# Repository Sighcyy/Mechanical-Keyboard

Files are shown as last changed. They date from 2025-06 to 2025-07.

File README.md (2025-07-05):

# Mechanical Keyboard

I designed a 60% Mechanical Keyboard featuring 60+ push-button switches, a rotary encoder, and keystabilizers for larger keycaps. It features an EC11 rotary encoder,  the Raspberry Pi Pico microcontroller, which was chosen for its small form factor and support for KMK firmware. The parts are populated on a custom PCB for tidy arrangement and good performance. The case is fully 3D printable, making the design easy to reproduce and customize. This keyboard provides a programmable  interface to enhance game control and portability rather than a larger keyboard. 

# Project Goal
This is my second official project, and the reason I wanted to implement this is that I wanted to work more in-depth with complex PCBs. Thus, I decided that a keyboard with a key matrix would be best, and routing all the switches would require using a lot more of the front-end and back-end copper layers, as well as vias. The purpose as a whole was not to try to follow any guides too much and just research a lot more in order to understand things. I felt like this would build a stronger sense of passion and understanding for the subject rather than blindly following a DIY guide. 

# BOM : 
*Shipping is included in the cost

*You may notice that I use Amazon a lot. I have Amazon Prime, and when comparing that to buying from somewhere with high shipping costs and potentially lower quality, I chose Amazon Prime.
| Name  | Vendor | Cost | Link |
| --- | --- | --- | --- |
| 1N4148WT Diodes x 100  | DigiKey  | ~$14.56  | [Link](https://www.digikey.com/en/products/detail/onsemi/1N4148WT/2094398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) |
| Keycaps ( Purple and Black)  | Amazon  | $14.59 |[Link](https://www.amazon.com/gp/product/B0C1BLFFKJ/ref=ewc_pr_img_1?smid=A2X78RSRFYCZMR&th=1)|
| PLA 1.75mm 3D Printer Filament  | Amazon  | $9.99  | [Link](https://www.amazon.com/Filament-Dimensional-Accuracy-Clogging-Cardboard/dp/B0DCJR8JTG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) |
| Rotary Encoder + Cap  | Amazon  | $8.88  | [Link](https://www.adafruit.com/product/5454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) |
| Gateron PCB Mounted Stabilizer  | Gateron  | $10.99  |[Link](https://www.gateron.com/products/gateron-pcb-mounted-stabilizer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) |
| Cherry MX Key Switches x 65 | Amazon  | $39.99  |[Link](https://www.amazon.com/Switches-Mechanical-Keyboards-Mounted-MX1AE1NN/dp/B09ZST8WMF?th=1) |
| Rasberry Pi Pico  | Amazon  | $8.99 | [Link](https://www.amazon.com/Raspberry-Pi-Pico/dp/B09KVB8LVR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) |
| M2.5 Screws | Amazon  | $3.78 | [Link](https://www.amazon.com/Stainless-Electrical-Attaching-Connectors-Furniture/dp/B0F1TX35J1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) |
| PCB | JLPCB  | $28.94 | [Link](https://cart.jlcpcb.com/quote?spm=Jlcpcb.Homepage.1006&spm=Jlcpcb.Homepage.1006) |

Approximate Total Cost:  $140.71

Rounded Total Cost (To Take Tax Into Account): $145

# PCB and Schematics Design




# CAD Model

Top Plate


Bottom Plate



Assembly with PCB


# Firmware Overview



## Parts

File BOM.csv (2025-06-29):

Name | Vendor | Cost | Link
1N4148WT Diodes x 100 | DigiKey | ~$14.56 | https://www.digikey.com/en/products/detail/onsemi/1N4148WT/2094398
Keycaps (Purple and Black) | Amazon | $14.59 | https://www.amazon.com/gp/product/B0C1BLFFKJ/ref=ewc_pr_img_1?smid=A2X78RSRFYCZMR&th=1
PLA 1.75mm 3D Printer Filament | Amazon | $9.99 | https://www.amazon.com/Filament-Dimensional-Accuracy-Clogging-Cardboard/dp/B0DCJR8JTG
Rotary Encoder + Cap | Amazon | $8.88 | https://www.adafruit.com/product/5454
Gateron PCB Mounted Stabilizer | Gateron | $10.99 | https://www.gateron.com/products/gateron-pcb-mounted-stabilizer?VariantsId=10538
Cherry MX Key Switches x 65 | Amazon | $39.99 | https://www.amazon.com/Switches-Mechanical-Keyboards-Mounted-MX1AE1NN/dp/B09ZST8WMF
Raspberry Pi Pico | Amazon | $8.99 | https://www.amazon.com/Raspberry-Pi-Pico/dp/B09KVB8LVR
M2.5 Screws | Amazon | $3.78 | https://www.amazon.com/Stainless-Electrical-Attaching-Connectors-Furniture/dp/B0F1TX35J1
PCB | JLCPCB | $28.94 | https://cart.jlcpcb.com/quote?spm=Jlcpcb.Homepage.1006
___ | Total | $140.71 | _______
___ | Realistic Total | $145 | _______

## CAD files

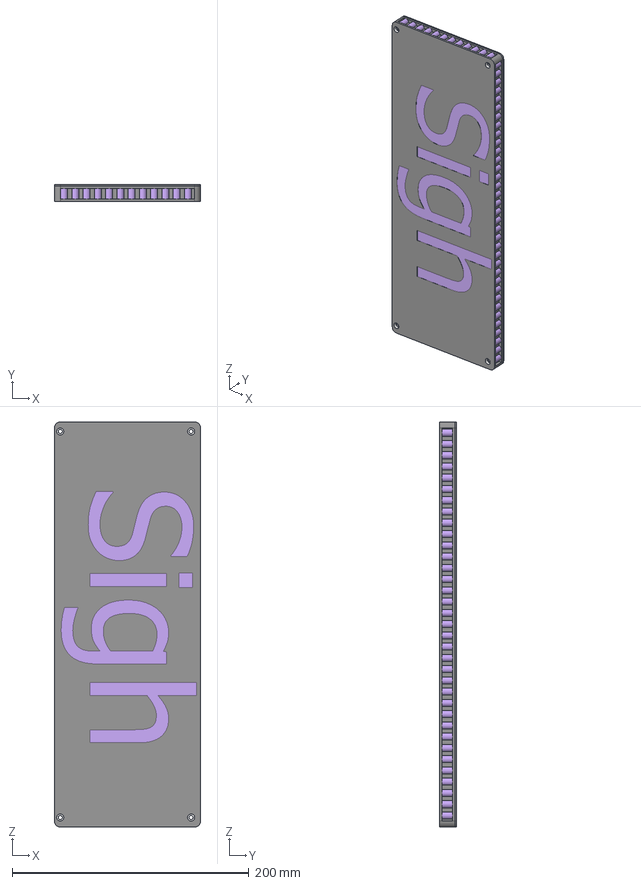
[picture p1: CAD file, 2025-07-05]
CAD/Assembly1.stp
123.5 x 14.5 x 341.8 mm
Top_Plate_Mkey
Bottom_Plate_MKey
D_SOD-523 x 63
FullSplit_Keyboard_PCB_PCB

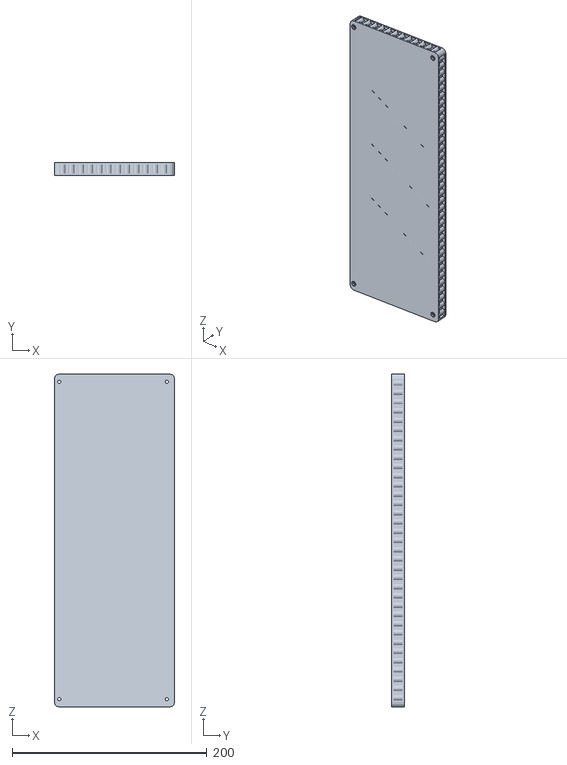
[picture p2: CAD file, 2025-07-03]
Production/Bottom_Plate_MKey.stl
123.5 x 13.0 x 341.8

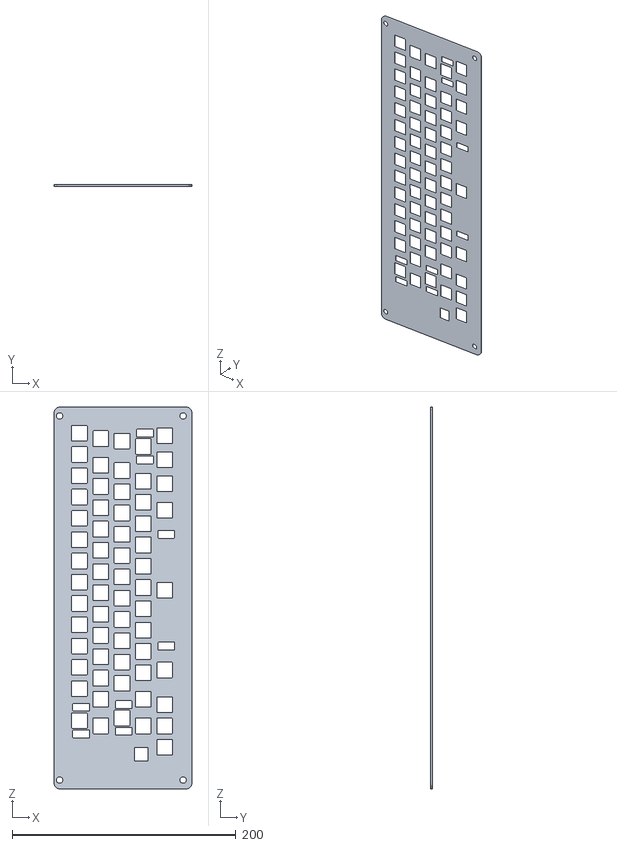
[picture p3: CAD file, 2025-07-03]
Production/Top_Plate_Mkey.stl
123.5 x 1.50 x 341.8

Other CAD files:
CAD/Bottom_Plate_MKey.stp
CAD/Top_Plate_Mkey.stp
CAD/Assembly1.iam
CAD/Assembly1.stl
CAD/Bottom_Plate_MKey.ipt
CAD/Bottom_Plate_MKey.stl
CAD/Top_Plate_Mkey.ipt

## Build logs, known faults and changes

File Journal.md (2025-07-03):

# June 20th, 2025
Time = ~4 hours

Today, I took the first step to advance to the next level in my keyboard journey. I started with a MacPad, but I did not use a matrix since I only had a few keys. Thus, my next project was going to be a Mechanical Keyboard.

Today, I conducted research and completed some overall planning for my project. With the matrix design, I had to take into account "ghosting", which I could easily avoid with some diodes. 

I did a couple of whiteboard drawings just to understand how many columns and rows I would need. Then I created my schematic based on my whiteboard drawing reference. 

D1_Schematics

I then went into what each key would represent so that I could get a better understanding of what the keyboard key layout would be like.

By doing this, I was able to remove some extra columns so that my keyboard would be much more portable.



Afterwards, I spent the rest of my time choosing the right footprints and placing all my parts properly on the PCB



# June 21th, 2025
Time = ~4 hours

Today, I focused on figuring out how to properly route all the key inputs on my PCB, which turned out to be more challenging than expected due to limited space and overlapping traces. I spent a lot of time experimenting with using the bottom copper layer and strategically placing vias to reduce congestion and avoid trace conflicts. This approach significantly streamlined the routing process and helped me finish the layout more efficiently. Along the way, I also picked up several helpful workflow shortcuts in KiCad, like quick via placement, net highlighting, and optimized trace routing, which should speed up my future designs and make the overall process smoother.



# June 22nd, 2025
Time = ~4 hours

Today was a productive day on the 3D modeling front, as I completed the main structure of the CAD model by designing both the top and bottom plates, following a similar approach to my earlier Macropad build. I used a keyboard layout editor to customize the key arrangement, then exported it as a DXF file to precisely cut switch holes into the top plate. While the design is still pretty minimal in terms of aesthetics, I decided to hold off on cosmetic features until later in the process. Instead, I shifted gears and began researching the firmware side—specifically how keymaps, layers, and matrix scanning are handled in microcontroller code—so I can better integrate the hardware and software components once the physical build is done.




# June 23rd, 2025
Time = ~4 hours

Today, I wrapped up writing the firmware for my keyboard using Python with the KMK framework. Thanks to the research I did yesterday on implementing diode-based matrix scanning and integrating a rotary encoder, the coding process went smoothly and efficiently. My prior experience with key assignments from my Macropad project also helped me set up the keymap and layers quickly. With the core functionality complete, I decided to spend some extra time refining the keyboard case design by adding custom inscriptions and decorative linings to give it a more polished and personalized look—details I believe will help the final product stand out both functionally and visually.




# June 24th, 2025
Time = ~4 hours

Since today was planned to be my final work session, I focused on wrapping up all remaining tasks to prepare for the build phase. I started by creating a complete Bill of Materials (BOM), which took some time due to the various key sizes and layout adjustments I had made—several non-standard key sizes required finding the right switch kit that could accommodate everything. I also researched PCB-mount stabilizers to match the layout and ensure proper key feel. In addition, I finalized my component list by selecting a compatible PCB, PLA filament for 3D printing the case, and a set of small screws and nuts to secure the top and bottom plates together. Most of the sourcing was done through Amazon, after comparing product specs and reviews to ensure everything matched my design needs. To finish off the day, I carefully reviewed the CAD model, double-checking all key dimensions and mounting points to catch any potential issues before manufacturing.

# July 7th, 2025
Big things, I wanted to do some quick changes. The keyboard itself was a little bland. Thus, I thought I would spend time today adding a little more uniqueness to it. I gave the edges of the keyboard a column-like aesthetic. The bottom had 3 large X's. Finally, for the actual top, I added the word 'PRIDE' in text. I thought it looked nice. 




Also, I wanted to make sure that if I painted it, I knew how it would loo,k so I added that into the design as well and finished up my design





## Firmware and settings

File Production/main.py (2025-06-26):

import board

from kmk.kmk_keyboard import KMKKeyboard
from kmk.scanners.keypad import KeysScanner
from kmk.keys import KC
from kmk.scanners import DiodeOrientation
from kmk.extensions.media_keys import MediaKeys
from kmk.modules.encoder import EncoderHandler
from kmk.modules.macros import Press, Release, Tap, Macros



Column1 = board.D0
Column2 = board.D1
Column3 = board.D4
Column4 = board.D5
Column5 = board.D6
Column6 = board.D7
Column7 = board.D9
Column8 = board.D10
Column9 = board.D11
Column10 = board.D12
Column11 = board.D14
Column12 = board.D15
Column13 = board.D16
Column14 = board.D17


EncButton = board.D20

Row1 = board.D16
Row2 = board.D22
Row3 = board.D24
Row4 = board.D25
Row5 = board.D26

EncRotA = board.D27
EncRotB = board.D29

# Keyboard Main Instance
keyboard = KMKKeyboard()
keyboard.diode_orientation = DiodeOrientation.COL2ROW

# Encoder settings
encoder_handler = EncoderHandler()
keyboard.modules.append(encoder_handler)
encoder_handler.pins = ((EncRotA, EncRotB, EncButton, False),)
encoder_handler.map = (((KC.VOLD, KC.VOLU, KC.MUTE)



#Defining the Pins
keyboard.keymap = [
    [KC.GRAVE, KC.KP_1, KC.KP_2, KC.KP_3, KC.KP_4, KC.KP_5, KC.KP_6, KC.KP_7, KC.KP_8, KC.KP_9, KC.KP_0, KC.MINUS, KC.EQUAL, KC.BSPACE,
     KC.TAB	, KC.Q, KC.W, KC.E, KC.R, KC.T, KC.Y, KC.U, KC.I, KC.O, KC.P, KC.KC.LBRACKET, KC.RBRACKET, KC.BSLASH,
     KC.LOCKING_CAPS, KC.A, KC.S, KC.D, KC.F, KC.G, KC.H, KC.J, KC.K, KC.L, KC.SCOLON, KC.QUOTE, KC.KP_ENTER	
     KC.LSHIFT, KC.Z, KC.X, KC.C, KC.V, KC.B, KC.N, KC.M, KC.COMMA, KC.DOT, KC.SLASH, KC.RSHIFT, KC.UP
     KC.LCTRL, KC.NO, KC.LGUI, KC.LALT, KC.SPACE, KC.RALT, KC.LEFT, KC.DOWN, KC.RIGHT
    ]
]
                        

                        

                        

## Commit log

2025-06-29 Create BOM
2025-06-29 Update and rename BOM to BOM.csv
    [BOM.csv]
